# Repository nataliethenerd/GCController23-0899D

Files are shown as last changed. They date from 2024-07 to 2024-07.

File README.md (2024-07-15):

# Game Cube Controller 23-0899D reverse engineer

gcc

**ORDER WITH ENIG**

Thanks to the people who have supported me on Ko-Fi, you've made this possible! 

You can support me on Ko-Fi



## Scans

HD scans of the original board can be found [here](https://github.com/nataliethenerd/boardscans/tree/main/GCC-23-0899D)

**My socials**

• [Twitter](https://twitter.com/natalie_thenerd) 

• [Instagram](https://www.instagram.com/natalie.thenerd/) 

• [Modded Gameboy Club](https://moddedgameboy.club/) - a club dedicated to the modification of Game Boys, freely sharing resources

## License

Please do not remove my logo, website and name.



The CC BY-SA 4.0 (Creative Commons Attribution-ShareAlike 4.0 International) license allows you to:

1. **Share** - Copy and redistribute the material in any medium or format.
2. **Adapt** - Remix, transform, and build upon the material for any purpose, even commercially.

### Conditions:

- **Attribution** - You must give appropriate credit, provide a link to the license, and indicate if changes were made. You may do so in any reasonable manner, but not in any way that suggests the licensor endorses you or your use.
- **ShareAlike** - If you remix, transform, or build upon the material, you must distribute your contributions under the same license as the original.

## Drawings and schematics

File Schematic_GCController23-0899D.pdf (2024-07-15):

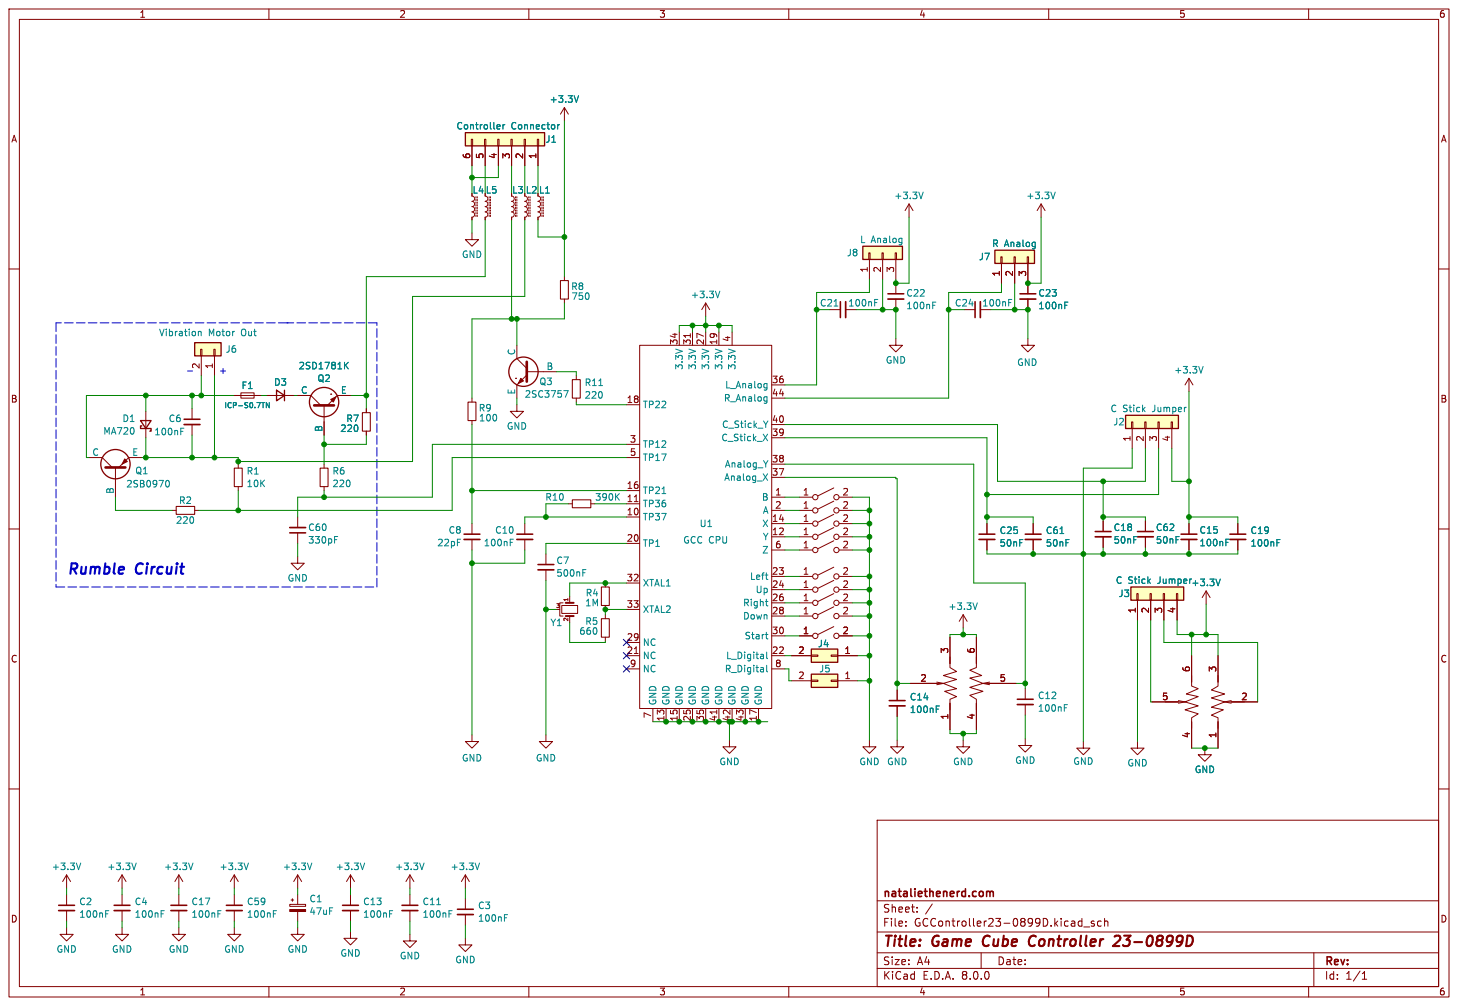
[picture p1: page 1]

File: GCController23-0899D.kicad_sch Sheet: / nataliethenerd.com

Id: 1/1 Title: Game Cube Controller 23-0899D

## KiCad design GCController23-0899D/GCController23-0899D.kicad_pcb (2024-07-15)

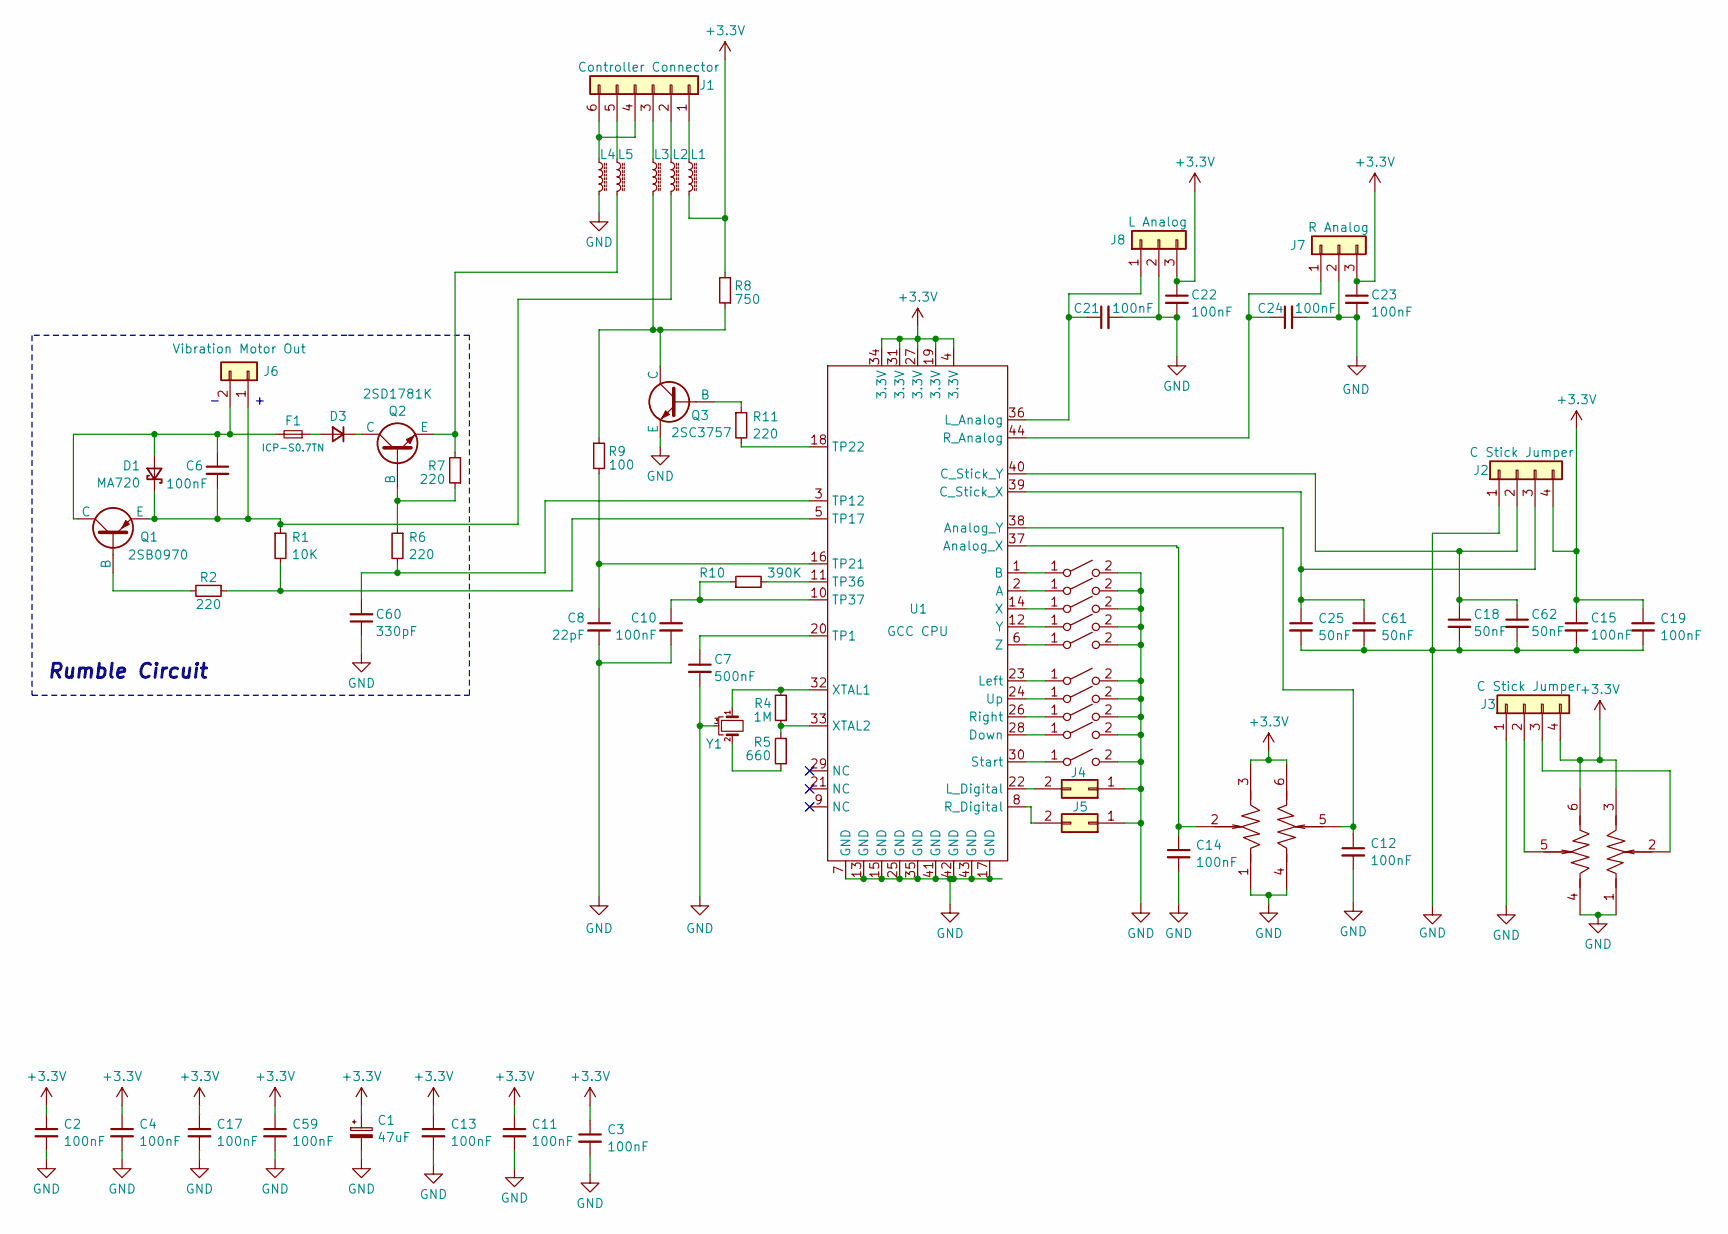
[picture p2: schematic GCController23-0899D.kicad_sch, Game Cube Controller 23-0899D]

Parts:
C1: 47uF; GCC_cap
C2, C3, C4, C6, C10, C11, C12, C13, C14, C15, C17, C19, C21, C22, C23, C24, C59: 100nF; C_0603_1608Metric
C7: 500nF; C_0603_1608Metric
C8: 22pF; C_0603_1608Metric
C18, C25, C61, C62: 50nF; C_0603_1608Metric
C60: 330pF; C_0603_1608Metric
D1: MA720; SOT-23
D3: D_Small; D_SOD-323_HandSoldering
F1: ICP-S0.7TN; Fuse_1210_3225Metric
J1: Controller Connector; PinSocket_1x06_P2.00mm_Vertical
J2, J3: C Stick Jumper; PinHeader_1x04_P2.00mm_Vertical
J4: L; GCC_DPad
J5: R; GCC_DPad
J6: Vibration Motor Out; SolderJumper-2_P1.3mm_Open_RoundedPad1.0x1.5mm
J7: R Analog; PinHeader_1x03_P2.54mm_Vertical
J8: L Analog; PinHeader_1x03_P2.54mm_Vertical
L1, L2, L4, L5: FerriteBead_Small; R_0805_2012Metric
L3: FerriteBead_Small; R_0603_1608Metric
Q1: 2SB0970; SOT-23
Q2: 2SD1781K; SOT-23
Q3: 2SC3757; SOT-323_SC-70
R1: 10K; R_0603_1608Metric
R2, R6, R7, R11: 220; R_0603_1608Metric
R4: 1M; R_0603_1608Metric
R5: 660; R_0603_1608Metric
R8: 750; R_0603_1608Metric
R9: 100; R_0603_1608Metric
R10: 390K; R_0603_1608Metric
SW1, SW2, SW7, SW8: SW_SPST; GCC_DPad
SW3, SW4, SW5, SW6: SW_SPST; GCC_ABXY
SW9: SW_SPST; GCC_Start
SW10: 3D161; GCC_CStick; LCSC Part C92593
SW11: SW_SPST
SW13: 3D161; GCC_Joystick; LCSC Part C92593
U1: GCC CPU; GCC_CPU
Y1: Crystal_GND3_Small; Resonator_SMD_Murata_CSTxExxV-3Pin_3.0x1.1mm

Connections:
+3.3V: C1.1, C2.1, C3.1, C4.1, C11.1, C13.1, C15.1, C17.1, C19.1, C22.1, C23.1, C59.1, J2.4, J3.4, J7.3, J8.3, L1.1, R8.2, SW10.3, SW10.6, SW13.3, SW13.6, U1.4 (3.3V), U1.19 (3.3V), U1.27 (3.3V), U1.31 (3.3V), U1.34 (3.3V)
GND: C1.2, C2.2, C3.2, C4.2, C7.2, C8.2, C10.2, C11.2, C12.2, C13.2, C14.2, C15.2, C17.2, C18.2, C19.2, C21.2, C22.2, C23.2, C24.2, C25.2, C59.2, C60.1, C61.2, C62.2, J2.1, J3.1, J4.1, J5.1, J7.2, J8.2, L4.2, Q3.2 (E), SW1.2 (B), SW2.2 (B), SW3.2 (B), SW4.2 (B), SW5.2 (B), SW6.2 (B), SW7.2 (B), SW8.2 (B), SW9.2 (B), SW10.1, SW10.4, SW11.2 (B), SW13.1, SW13.4, U1.7 (GND), U1.13 (GND), U1.15 (GND), U1.17 (GND), U1.25 (GND), U1.35 (GND), U1.41 (GND), U1.42 (GND), U1.43 (GND), Y1.3; also elsewhere on the board
unnamed: C6.1, D1.1 (A), F1.2, J6.2, Q1.3 (C)
unnamed: C6.2, D1.3 (K), J6.1, L2.2, Q1.2 (E), R1.1
unnamed: D3.2 (A), F1.1
unnamed: D3.1 (K), Q2.3 (C)
unnamed: J1.1, L1.2
unnamed: J1.2, L2.1
unnamed: J1.3, L3.1
unnamed: J1.4, J1.6, L4.1
unnamed: J1.5, L5.2
unnamed: C18.1, C62.1, J2.2, U1.40 (C_Stick_Y)
unnamed: C25.1, C61.1, J2.3, U1.39 (C_Stick_X)
unnamed: J3.2, SW10.5
unnamed: J3.3, SW10.2
unnamed 15: J4.2, U1.22 (L_Digital); also elsewhere on the board
unnamed 16: J5.2, U1.8 (R_Digital); also elsewhere on the board
unnamed: C24.1, J7.1, U1.44 (R_Analog)
unnamed: C21.1, J8.1, U1.36 (L_Analog)
unnamed: Q1.1 (B), R2.2
unnamed: Q2.2 (B), R6.1, R7.1
unnamed: L5.1, Q2.1 (E), R7.2
unnamed: Q3.1 (B), R11.1
unnamed: L3.2, Q3.3 (C), R8.1, R9.1
unnamed: R5.1, Y1.2
unnamed: SW1.1 (A), U1.24 (Up)
unnamed: SW2.1 (A), U1.23 (Left)
unnamed: SW3.1 (A), U1.14 (X)
unnamed: SW4.1 (A), U1.12 (Y)
unnamed: SW5.1 (A), U1.1 (B)
unnamed: SW6.1 (A), U1.2 (A)
unnamed: SW7.1 (A), U1.26 (Right)
unnamed: SW8.1 (A), U1.28 (Down)
unnamed: SW9.1 (A), U1.30 (Start)
unnamed: SW11.1 (A), U1.6 (Z)
unnamed: C14.1, SW13.2, U1.37 (Analog_X)
unnamed: C12.1, SW13.5, U1.38 (Analog_Y)
unnamed: C7.1, U1.20 (TP1)
unnamed: C60.2, R6.2, U1.3 (TP12)
unnamed: R1.2, R2.1, U1.5 (TP17)
unnamed: C8.1, R9.2, U1.16 (TP21)
unnamed: R11.2, U1.18 (TP22)
unnamed: R10.2, U1.11 (TP36)
unnamed: C10.1, R10.1, U1.10 (TP37)
unnamed: R4.2, U1.32 (XTAL1), Y1.1
unnamed: R4.1, R5.2, U1.33 (XTAL2)

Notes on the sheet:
Rumble Circuit

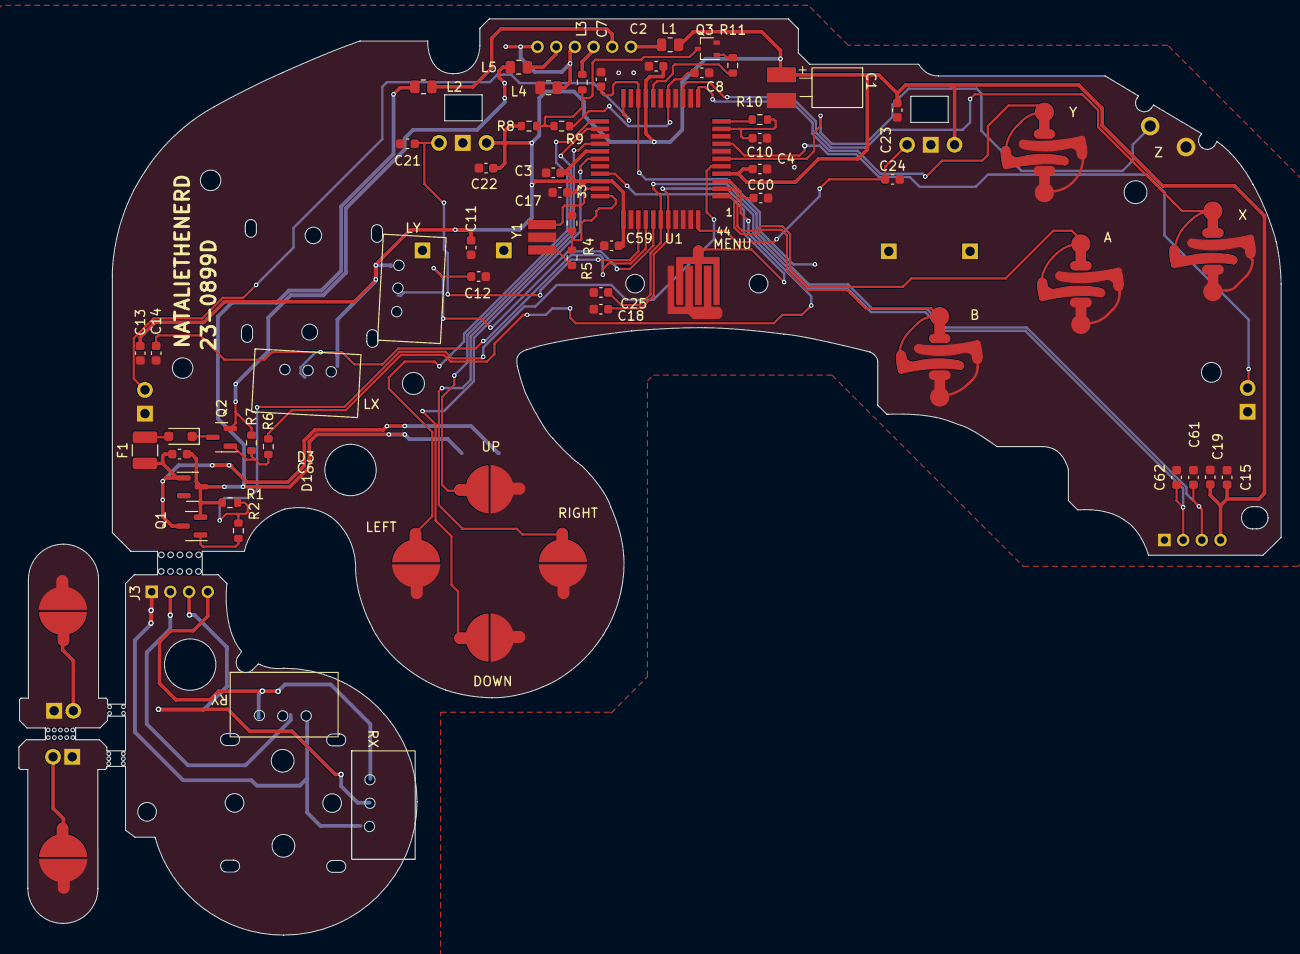
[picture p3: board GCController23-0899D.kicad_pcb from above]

Board: 4 copper layers, 135.1 x 98.0 mm, 68 parts (0 on the bottom side), 45 nets.

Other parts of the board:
SW10#2, SW12: SW_SPST; PinHeader_1x02_P2.54mm_Vertical

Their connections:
GND: SW10#2.2 (B), SW12.2 (B); also elsewhere on the board
unnamed 15: SW10#2.1 (A); also elsewhere on the board
unnamed 16: SW12.1 (A); also elsewhere on the board

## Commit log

2024-07-15 kicad files
    [GCController23-0899D.kicad_pcb, GCController23-0899D.kicad_sch]
2024-07-15 added open source logo :smile:
    [GCController23-0899D.kicad_pcb]
2024-09-16 pdf schematics
